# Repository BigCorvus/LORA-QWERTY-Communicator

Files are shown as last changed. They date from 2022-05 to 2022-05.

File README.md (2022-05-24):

# LORA-QWERTY-Communicator
A tidy, versatile and feature-packed LORA QWERTY communication device mainly based on a Blackberry Q10 keyboard, nRF52840, SX1262 and a 2.7'' Sharp Memory LCD (LS027B7DH01).
I created this because I wanted to practice a little and put some components that I had laying around to good use. The system had to have a low power consumption and outdoor usability, hence the component choices. The SX1262 draws 4,6mA in RX mode and the nRF52 can poll the keyboard while also drawing little power. Without optimizing anything I got 12mA. This can be further reduced by turning off some sensors. The unit can monitor its own power consumption and battery charge status via a BQ27441 Lithium Fuel Gauge.  
finished devices  

Some words about the memory LCDs: I got fake ones from Ali and only one out of three works properly! One consumes 20mA instead of ~400µA and one had some dead pixels after some days of usage (seen on the pictures). They are not that much cheaper (~25 vs ca 32$), so avoid them and only get genuine SHARP displays from digikey or so.  
There is a passive piezo buzzer (9032 type) and a vibration motor ("10x4mm" look on Aliexpress) for notification purposes. A BME280 can be soldered for altimeter functionality. A DS3231M RTC is supposed to keep time (the wires on the images are for optional backup battery connection). A MPU9250 9-DOF IMU was included to act as a tilt-compensated compass or for air mouse functionality. A GD25Q16CE QSPI flash (apparently optional, not required by the bootloader, works with mass storage TinyUSB test sketch) and an µSD card slot for storage of for example chat history or sensor values. An optional GPS module can be connected to the exposed connector at the top of the device. I used a BN220 which fits into the enclosure if you use an appropriate LiPo cell. All I2C sensor are on one I2C bus and are optional. They do not need to be populated. Time and altitude can just as well be fetched via GPS. The connector for the Q10 keyboard is a Hirose BM14B(0.8)-24DS-0.4V(53)     

open devices  
open devices 2  

The repository contains the EAGLE PCB design files, gerber, pick and place and BOM files, Solidworks design files and .STL for a perfectly fitting enclosure and an Arduino test sketch to test most of the system components. The enclosure lacks inserts for the pushbutton and slide swith. This I will add in the future. You require 4 2mmx10mm plastic screws to hold it together. The resulting device has a thickness of only about 13,5mm.  
While the hardware is confirmed working (only one minor bug had to be fixed in the prototype - conflicting I2C addresses), the firmware part is very raw and has yet to be developed. Unfortunately I lack time desperately for such hobby things at the moment. What I had in mind for this device is mainly something like an encrypted "apocalypse" LORA communicator, maybe even based on Meshtastic. It can also communicate with other BLE devices and acquire, log and share sensor data or act as a USB or BLE HID keyboard. The test firmware is based on the Adafruit nRF52 core v1.0.0. In order for the device to be programmable via the Arduino IDE, the Feather nRF52840 Express bootloader has to be flashed, which I usually do via a J-Link and the Arduino IDE ("Burn Bootloader"). The bootloader can be activated at any time double-pulling the reset pin low. In a future revision there should also be reset button for that purpose, now there is at least a test point. The variant files for the Feather nRF52840 express need to be modified as well before programming the board. They are provided with the test sketch together with a readme.  

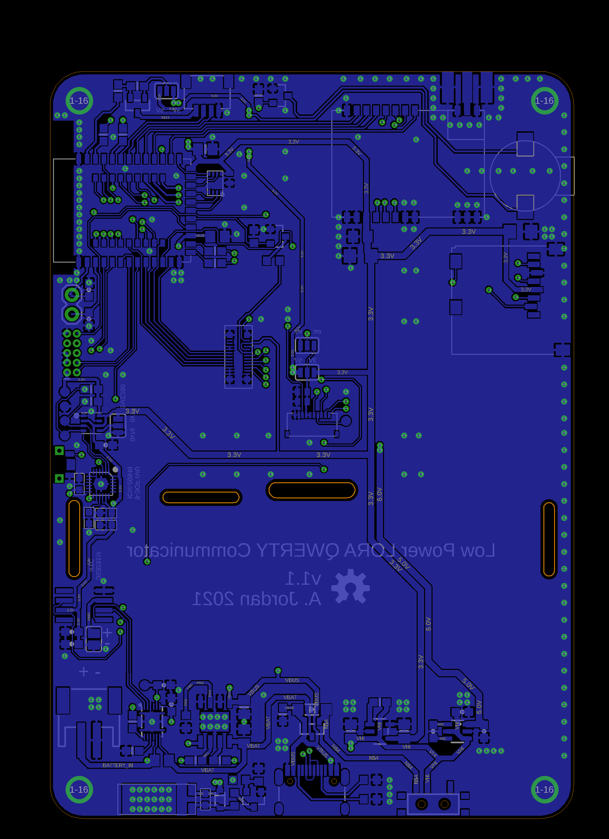
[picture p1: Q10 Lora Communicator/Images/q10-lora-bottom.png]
bottom
  
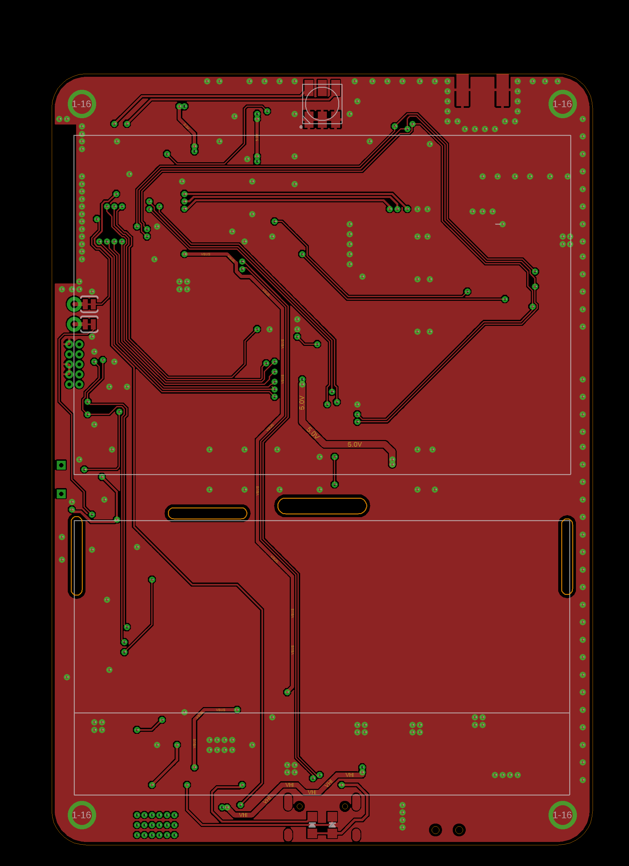
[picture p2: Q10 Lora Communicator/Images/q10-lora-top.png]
top
  
schematics

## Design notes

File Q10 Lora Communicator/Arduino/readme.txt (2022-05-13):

Before running the sketch, the adafruit feather express variant files have to be replaced with the provided ones first. They are located here under Windows:
C:\Users\xxxxxxxxx\AppData\Local\Arduino15\packages\adafruit\hardware\nrf52\1.0.0\variants

The feather nrf52840 express bootloader needs to be flashed via a segger jlink and the Arduino IDE.

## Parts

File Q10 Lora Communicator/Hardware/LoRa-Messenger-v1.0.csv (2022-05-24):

Part | Value | Device | Package | Description | DATASHEET | DIGIKEY | ELEMENT14 | OTHER | PROD_ID | SPICEPREFIX | TP_SIGNAL_NAME | URL | VALUE
1V8 | TPSQTP13R | TPSQTP13R | TP13R | Test pad
3V | TPSQTP13R | TPSQTP13R | TP13R | Test pad
ANT |  | SMACONNECTOR_EDGE | SMA_EDGELAUNCH | SMA Connector
C1 | 10µ | C-EUC0805 | C0805 | CAPACITOR, European symbol |  |  |  |  |  | C
C2 | 1.0uF | 1.0UF-16V-10%(0603) | 0603-CAP | CAP-00868 |  |  |  |  | CAP-00868 |  |  |  | 1.0uF
C3 | 100n | C-EUC0402 | C0402 | CAPACITOR, European symbol
C4 | 0.47uF | CAP0603-CAP | 0603-CAP | Capacitor |  |  |  |  | CAP-13216
C5 | 1.0uF | 1.0UF-16V-10%(0603) | 0603-CAP | CAP-00868 |  |  |  |  | CAP-00868 |  |  |  | 1.0uF
C6 | 10uF | CAP_CERAMIC0805-NOOUTLINE | 0805-NO | Ceramic Capacitors
C7 | 10uF | CAP_CERAMIC0805-NOOUTLINE | 0805-NO | Ceramic Capacitors
C8 | 10uF | CAP_CERAMIC0805-NOOUTLINE | 0805-NO | Ceramic Capacitors
C9 | 10µ | C-EUC0805 | C0805 | CAPACITOR, European symbol |  |  |  |  |  | C
C10 | 10uF | CAP_CERAMIC0805-NOOUTLINE | 0805-NO | Ceramic Capacitors
C11 | 10uF | 1.0UF-16V-10%(0603) | 0603-CAP | CAP-00868 |  |  |  |  | CAP-00868 |  |  |  | 1.0uF
C12 | 10nF 10% | CAP-0603 | C0603 | Ceramic Capacitors
C13 | 1µF | C-EUC0402 | C0402 | CAPACITOR, European symbol
C14 | 130pf | 1.0UF-16V-10%(0603) | 0603-CAP | CAP-00868 |  |  |  |  | CAP-00868 |  |  |  | 1.0uF
C15 | 100n | C-EUC0402 | C0402 | CAPACITOR, European symbol
C16 | 100nF 10% | CAP-0603 | C0603 | Ceramic Capacitors
C17 | 10uF | 1.0UF-16V-10%(0603) | 0603-CAP | CAP-00868 |  |  |  |  | CAP-00868 |  |  |  | 1.0uF
C18 | 100nF 10% | CAP-0603 | C0603 | Ceramic Capacitors
C19 | 130pf | 1.0UF-16V-10%(0603) | 0603-CAP | CAP-00868 |  |  |  |  | CAP-00868 |  |  |  | 1.0uF
C20 | 100µ | C-EUC1206 | C1206 | CAPACITOR, European symbol |  |  |  |  |  | C
C21 | 100µ | C-EUC1206 | C1206 | CAPACITOR, European symbol |  |  |  |  |  | C
C22 | 100n | 1.0UF-16V-10%(0603) | 0603-CAP | CAP-00868 |  |  |  |  | CAP-00868 |  |  |  | 1.0uF
C23 | 10µ | C-EUC0805 | C0805 | CAPACITOR, European symbol |  |  |  |  |  | C
C24 | 100nF 10% | CAP-0603 | C0603 | Ceramic Capacitors
C25 | 100nF 10% | CAP-0603 | C0603 | Ceramic Capacitors
C26 | 100n | 1.0UF-16V-10%(0603) | 0603-CAP | CAP-00868 |  |  |  |  | CAP-00868 |  |  |  | 1.0uF
C27 | 1µ | 1.0UF-16V-10%(0603) | 0603-CAP | CAP-00868 |  |  |  |  | CAP-00868 |  |  |  | 1.0uF
D1 | MBR120 | DIODE-SCHOTTKYSOD-123 | SOD-123
D3 | RED | LED0805_NOOUTLINE | CHIPLED_0805_NOOUTLINE | LED
D5 | RED | LED0805_NOOUTLINE | CHIPLED_0805_NOOUTLINE | LED
D6 | BAT20J | DIODE-SCHOTTKY-BAT20J | SOD-323 | Schottky diodes in SFE's production catalog |  |  |  |  | DIO-11623 |  |  |  | BAT20J
DWN2 | LS12T2 | LS12T2 | LS12T2
EXTC. | TPSQTP13R | TPSQTP13R | TP13R | Test pad
GND | TPSQTP13R | TPSQTP13R | TP13R | Test pad
IC1 | AP3602 | AP3602 | SOT23-6
IC2 | GD25Q16 | SPIFLASH_8PINUX | USON8 | SOIC8 SPI Flash
J2 |  | USB_C16PIN | USB-C-16P | USB Type C 16Pin Connector |  |  |  |  | CONN-14122
J3 | CORTEX_JTAG_DEBUG_MINIMUM_PTH_NS | CORTEX_JTAG_DEBUG_MINIMUM_PTH_NS | 2X5-PTH-1.27MM-NO_SILK | Cortex Debug Connector - 10 pin
JP2 |  | M02PTH | 1X02 | Standard 2-pin 0.1 header. Use with"
LED1 | RGBLED5050 | RGBLED5050 | RGBLED5050 | For 5050 RGB LEDs, the order of the LEDs may vary from one manufacturer to another!
Q2 | DMG2305 | MOSFET-P | SOT23-R | P-Channel Mosfet
Q3 | DMG2305 | MOSFET-P | SOT23-R | P-Channel Mosfet
R1 | 100k | RESISTOR_0603_NOOUT | 0603-NO | Resistors
R2 | 100k | RESISTOR_0603_NOOUT | 0603-NO | Resistors
R3 | 1K | RESISTOR_0603_NOOUT | 0603-NO | Resistors
R4 | 1.1k | R-EU_R0603 | R0603 | RESISTOR, European symbol |  |  |  |  |  | R
R5 | 10mOhm | R-EU_R0805 | R0805 | RESISTOR, European symbol |  |  |  |  |  | R
R6 | 4k7 | RESISTOR_0603_NOOUT | 0603-NO | Resistors
R7 | 1K | RESISTOR_0603_NOOUT | 0603-NO | Resistors
R8 | 100k | R-EU_R0603 | R0603 | RESISTOR, European symbol
R9 | 4k7 | RESISTOR_0603_NOOUT | 0603-NO | Resistors
R10 | 10k | RESISTOR_0603_NOOUT | 0603-NO | Resistors
R11 | 10k | RESISTOR_0603_NOOUT | 0603-NO | Resistors
R12 | 5.1k | R-EU_R0603 | R0603 | RESISTOR, European symbol |  |  |  |  |  | R
R13 | 5.1k | R-EU_R0603 | R0603 | RESISTOR, European symbol |  |  |  |  |  | R
R14 | 68 | RESISTOR_0603_NOOUT | 0603-NO | Resistors
R15 | 68 | RESISTOR_0603_NOOUT | 0603-NO | Resistors
R16 | 1K | RESISTOR_0603_NOOUT | 0603-NO | Resistors
R17 | 1K | RESISTOR_0603_NOOUT | 0603-NO | Resistors
R18 | 47 | R-EU_R0603 | R0603 | RESISTOR, European symbol
R19 | 10k | R-EU_R0603 | R0603 | RESISTOR, European symbol
R20 | 100k | RESISTOR_0603_NOOUT | 0603-NO | Resistors
R21 | 10 | R-EU_R0603 | R0603 | RESISTOR, European symbol
R22 | 10k | R-EU_R0603 | R0603 | RESISTOR, European symbol
R23 | 68 | RESISTOR_0603_NOOUT | 0603-NO | Resistors
R26 | 1k | RESISTOR_0603_NOOUT | 0603-NO | Resistors
SCL | TPSQTP13R | TPSQTP13R | TP13R | Test pad
SDA | TPSQTP13R | TPSQTP13R | TP13R | Test pad
SJ1 |  | SOLDERJUMPER_2WAY-OLDS | SJ_3 | Solder Jumper
SJ2 |  | SOLDERJUMPER_2WAY-OLDS | SJ_3 | Solder Jumper
SJ3 |  | SOLDERJUMPER_2WAY-OLDS | SJ_3 | Solder Jumper
SJ4 |  | SJ | SJ | SMD solder JUMPER
SJ5 |  | SOLDERJUMPER_2WAY-OLDS | SJ_3 | Solder Jumper
SJ7 | SOLDERJUMPERTRACE | SOLDERJUMPERTRACE | SJ_2S-TRACE | Solder Jumper
SJ8 | SOLDERJUMPERTRACE | SOLDERJUMPERTRACE | SJ_2S-TRACE | Solder Jumper
U$2 | BUZZER | BUZZER | BUZZER |  | 9032 type
U$7 | Q10KEYBOARD | Q10KEYBOARD | Q10KEYBOARD |  | Hirose BM14B(0.8)-24DS-0.4V(53)
U$10 | AYF531035_SHARP_MEM_DISP | AYF531035_SHARP_MEM_DISP | AYF531035_Y5BW
U$14 | NRF52840 | NRF52840 | NRF52840MOD
U$17 | JST-SH-3 | JST-SH-3 | JST-SH-3
U$28 | N-CHANNEL-MOSFET-BSS138 | N-CHANNEL-MOSFET-BSS138 | SOT23-3 | N-Channel MOSFET Mode Field Effect Transistor | http://www.fairchildsemi.com/ds/BS/BSS138.pdf | BSS138TR-ND | 2323154 |  |  |  |  | http://au.element14.com/fairchild-semiconductor/bss138/mosfet-n-ch-50v-220ma-sot-23/dp/2323154
U$36 | SX1292-EBYTE | SX1292-EBYTE | SX1262_EBYTE
U$41 | N-CHANNEL-MOSFET-BSS138 | N-CHANNEL-MOSFET-BSS138 | SOT23-3 | N-Channel MOSFET Mode Field Effect Transistor | http://www.fairchildsemi.com/ds/BS/BSS138.pdf | BSS138TR-ND | 2323154 |  |  |  |  | http://au.element14.com/fairchild-semiconductor/bss138/mosfet-n-ch-50v-220ma-sot-23/dp/2323154
U$45 | SWITCH_SPDT | SWITCH_SPDT | KPS-1290 | SWCH-10651 |  |  |  |  | SWCH-10651
U$46 | VIBRO | VIBRO | VIBRO |  |  |  |  |  | 10x4mm surface mount vibration motor
U$47 | TP4056BETTER_TP4056 | TP4056BETTER_TP4056 | TP4056BETTER_SO-08
U$69 | DS3231M | DS3231M | SO8
U$74 | N-CHANNEL-MOSFET-BSS138 | N-CHANNEL-MOSFET-BSS138 | SOT23-3 | N-Channel MOSFET Mode Field Effect Transistor | http://www.fairchildsemi.com/ds/BS/BSS138.pdf | BSS138TR-ND | 2323154 |  |  |  |  | http://au.element14.com/fairchild-semiconductor/bss138/mosfet-n-ch-50v-220ma-sot-23/dp/2323154
U1 | BQ27441-G1 | BQ27441-G1 | PDSO-N12 |  |  |  |  |  | IC-13220
U2 | AP2112(3.3V) | VREG_SOT23-5 | SOT23-5 | SOT23-5 Fixed Voltage Regulators
U3 | BME280 | BME280 | BME280 | BME280 - Environmental Sensor (I2C + SPI)
U4 | MPU-9250 | MPU-9250 | LEAD-QFN24
X1 | JSTPH | CON_JST_PH_2PIN | JSTPH2 | JST 2-Pin Right-Angle Connector
X4 | microsd | MICROSD | MICROSD | MicroSD/Transflash Card Holder with SPI pinout

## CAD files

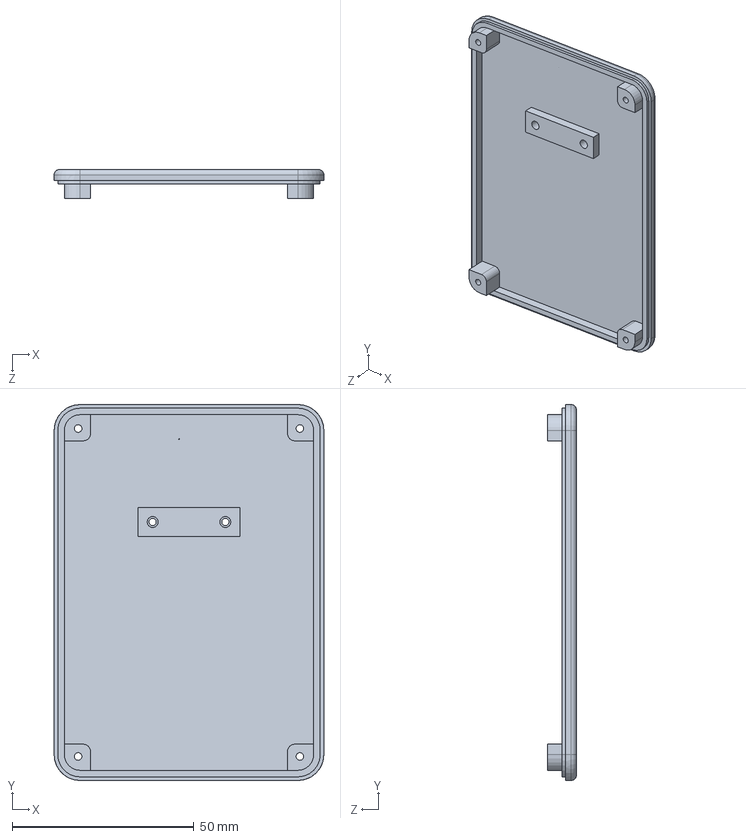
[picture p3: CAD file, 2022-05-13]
Q10 Lora Communicator/Hardware/enclosure/LORAmessengerBot.SLDPRT
74.2 x 103.4 x 8.00 mm

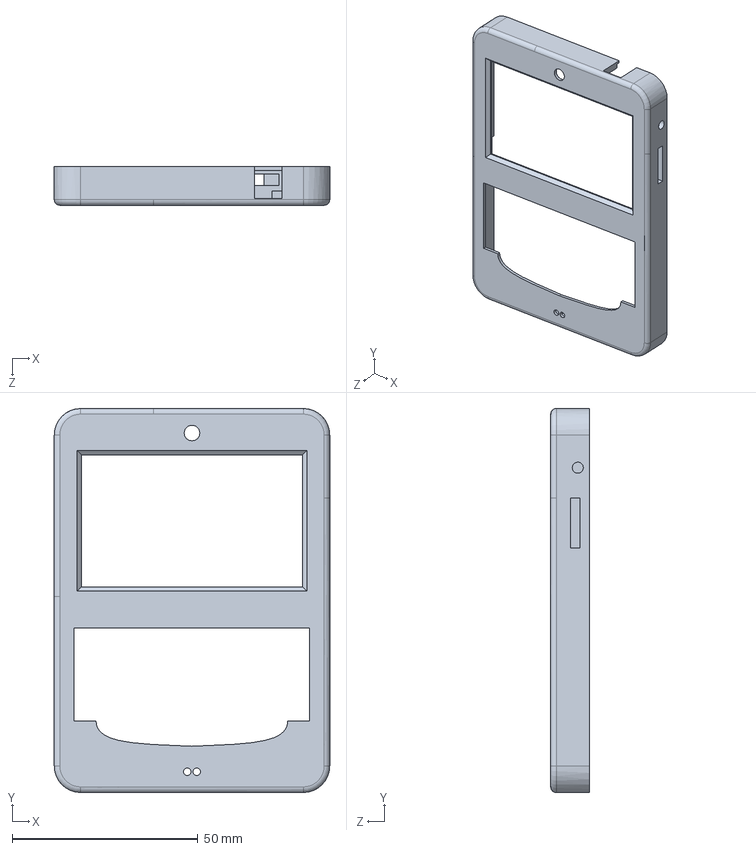
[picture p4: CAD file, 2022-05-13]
Q10 Lora Communicator/Hardware/enclosure/LORAmessengerTop.SLDPRT
74.2 x 103.4 x 10.4 mm

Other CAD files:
Q10 Lora Communicator/Hardware/enclosure/LORAmessengerBot.STL
Q10 Lora Communicator/Hardware/enclosure/LORAmessengerTop.STL

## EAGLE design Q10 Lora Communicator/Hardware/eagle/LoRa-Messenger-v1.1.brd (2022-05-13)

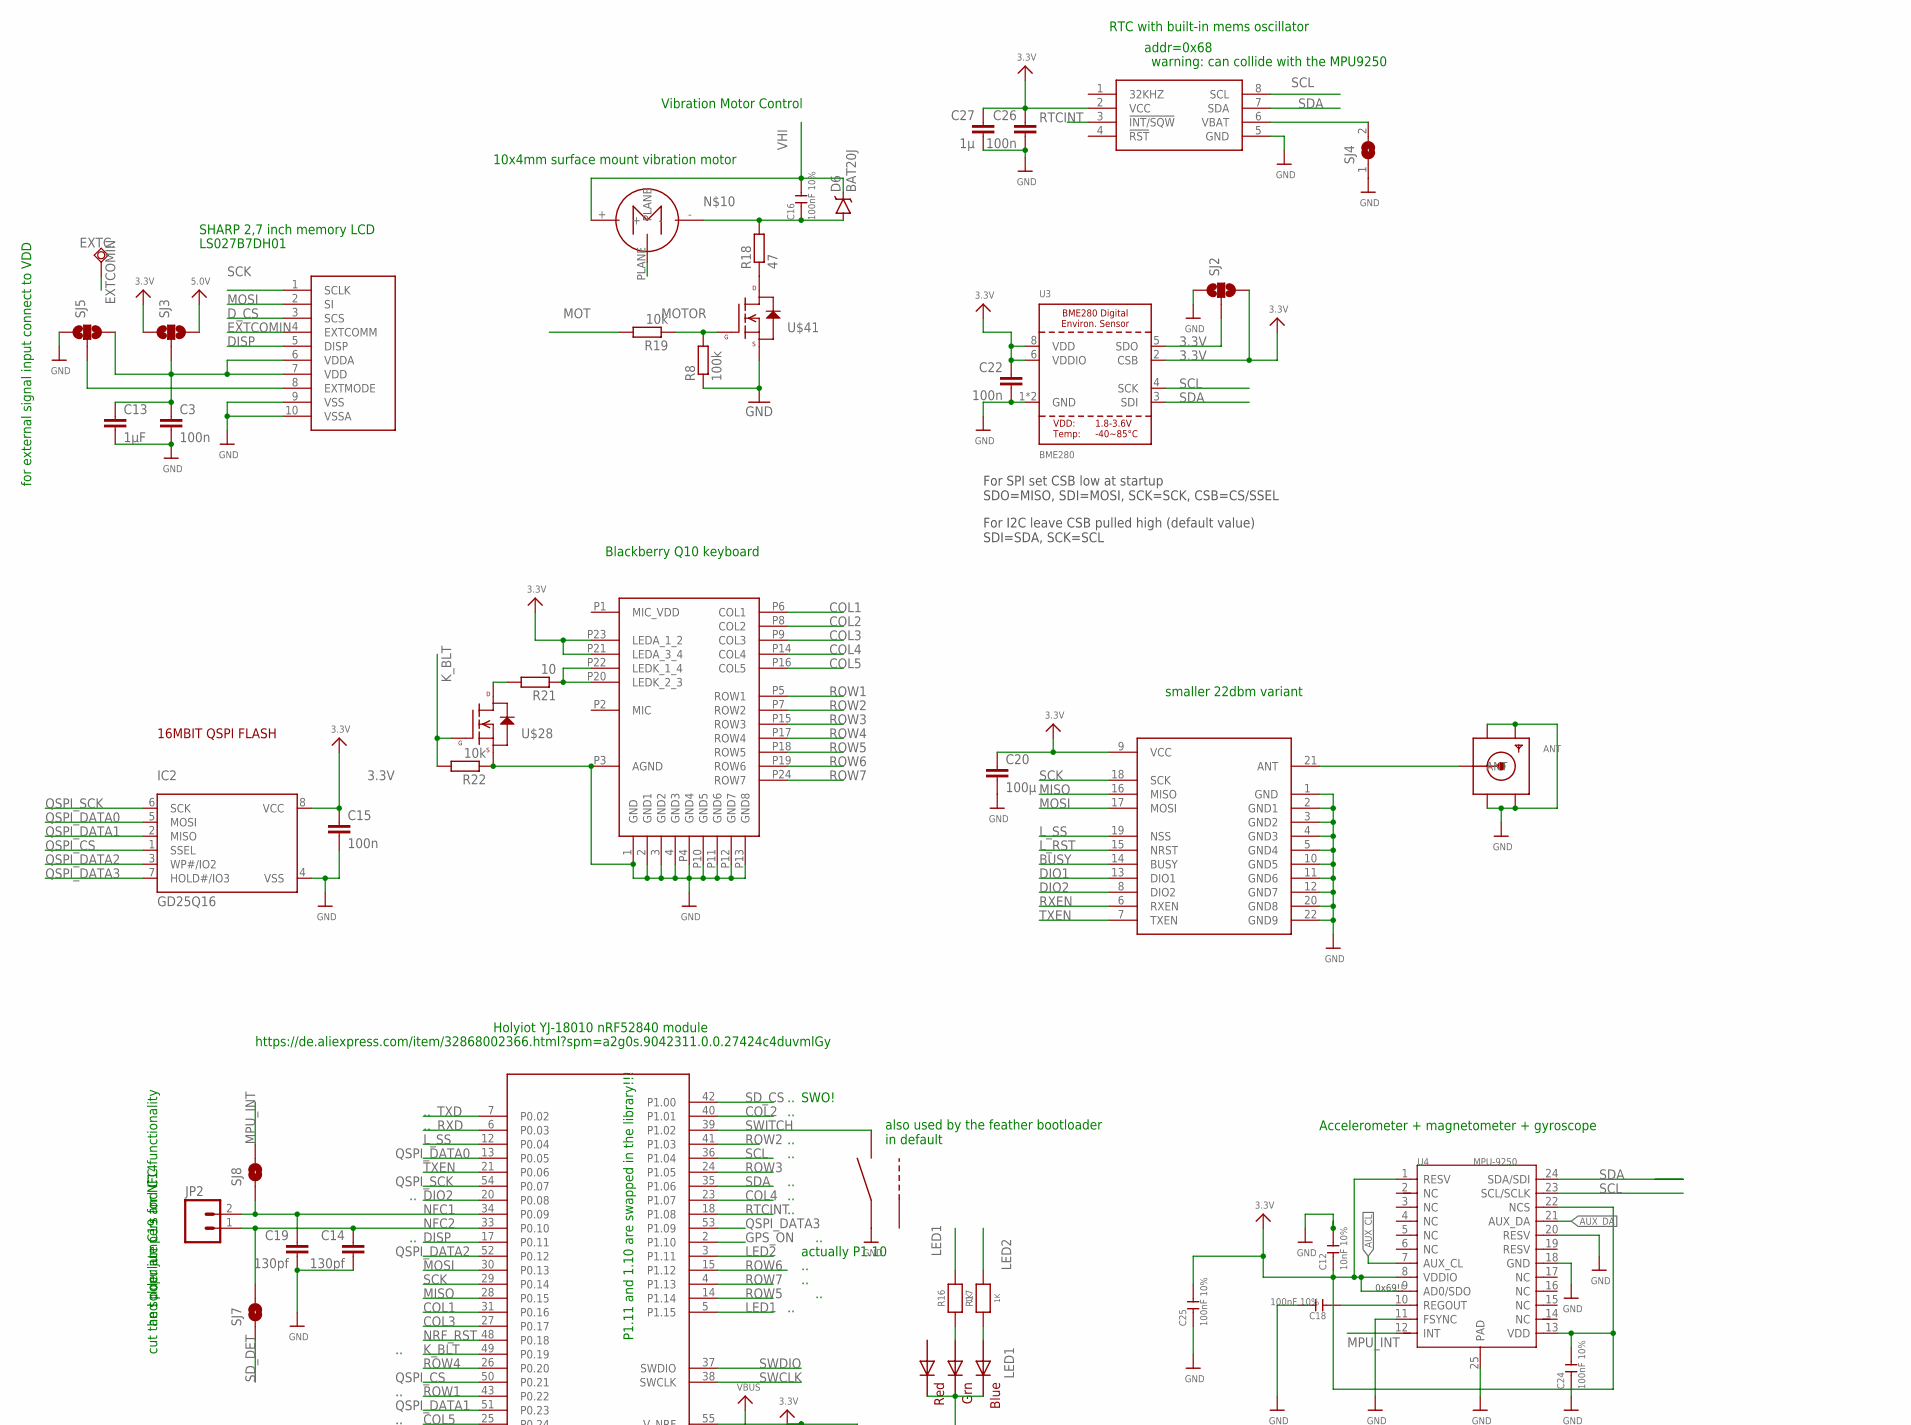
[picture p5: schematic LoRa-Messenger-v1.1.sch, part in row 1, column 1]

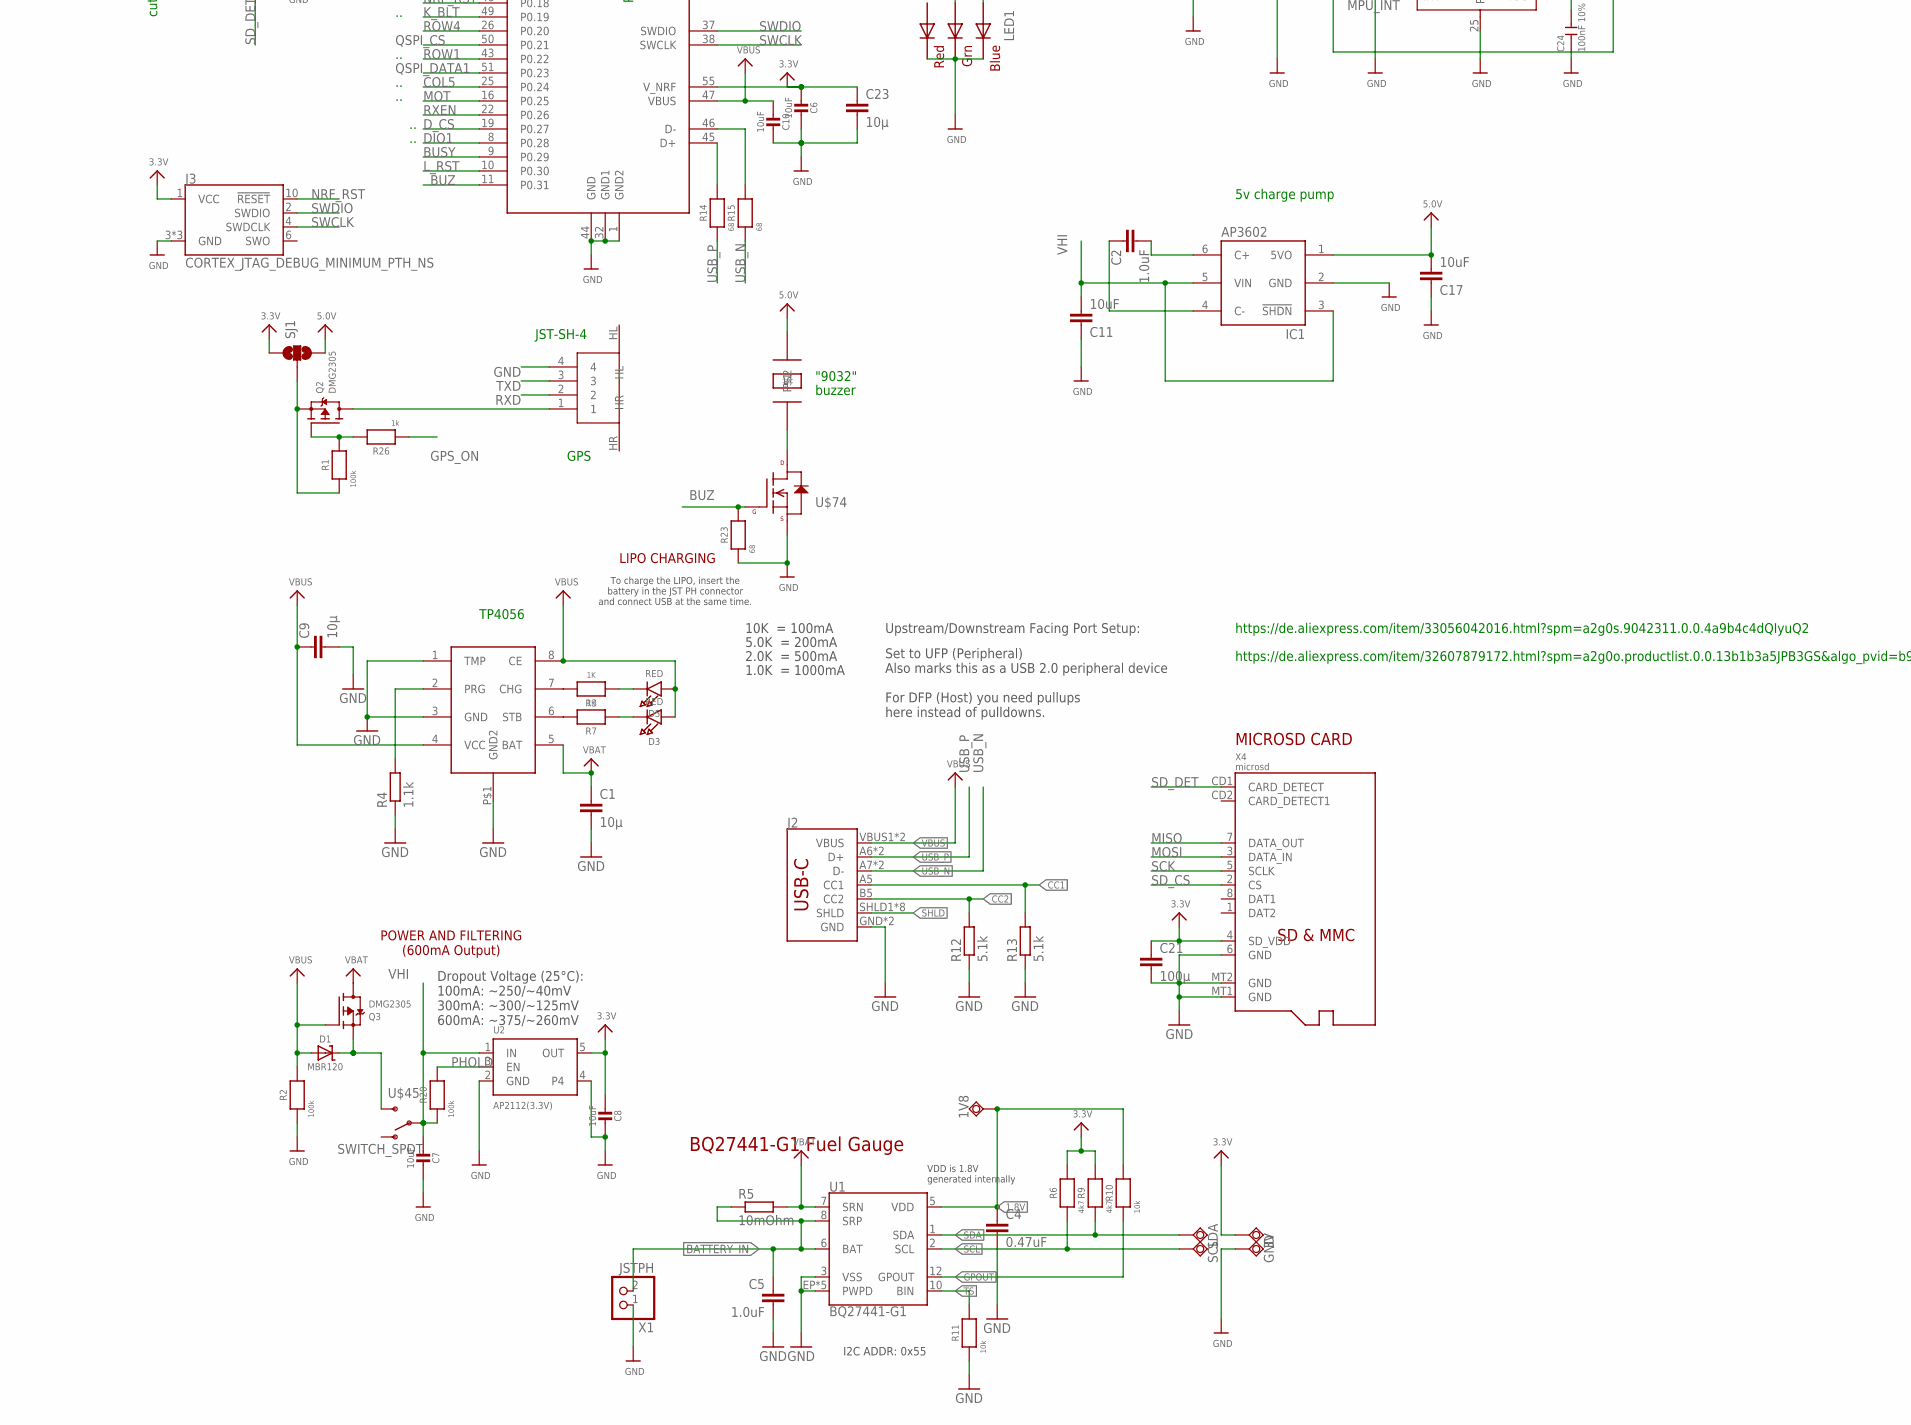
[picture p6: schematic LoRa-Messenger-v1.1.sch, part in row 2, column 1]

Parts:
1V8, 3V: TPSQTP13R; TP13R
ANT: SMACONNECTOR_EDGE; SMA_EDGELAUNCH
C1, C9, C23: 10µ; C0805
C2, C5: 1.0uF; 0603-CAP
C3, C15: 100n; C0402
C4: 0.47uF; 0603-CAP
C6, C7, C8, C10: 10uF; 0805-NO
C11, C17: 10uF; 0603-CAP
C12: 10nF 10%; C0603
C13: 1µF; C0402
C14, C19: 130pf; 0603-CAP
C16, C18, C24, C25: 100nF 10%; C0603
C20, C21: 100µ; C1206
C22, C26: 100n; 0603-CAP
C27: 1µ; 0603-CAP
D1: MBR120; SOD-123
D3, D5: RED; CHIPLED_0805_NOOUTLINE
D6: BAT20J; SOD-323
DWN2: LS12T2
EXTC.: TPSQTP13R; TP13R
GND: TPSQTP13R; TP13R
IC1: AP3602; SOT23-6
IC2: GD25Q16; USON8
J2: USB_C16PIN; USB-C-16P
J3: CORTEX_JTAG_DEBUG_MINIMUM_PTH_NS; 2X5-PTH-1.27MM-NO_SILK
JP2: M02PTH; 1X02
LED1: RGBLED5050
Q2, Q3: DMG2305; SOT23-R
R1, R2, R20: 100k; 0603-NO
R3, R7, R16, R17: 1K; 0603-NO
R4: 1.1k; R0603
R5: 10mOhm; R0805
R6, R9: 4k7; 0603-NO
R8: 100k; R0603
R10, R11: 10k; 0603-NO
R12, R13: 5.1k; R0603
R14, R15, R23: 68; 0603-NO
R18: 47; R0603
R19, R22: 10k; R0603
R21: 10; R0603
R26: 1k; 0603-NO
SCL: TPSQTP13R; TP13R
SDA: TPSQTP13R; TP13R
SJ1, SJ2, SJ3, SJ5: SOLDERJUMPER_2WAY-OLDS; SJ_3
SJ4: SJ
SJ7, SJ8: SOLDERJUMPERTRACE; SJ_2S-TRACE
U1: BQ27441-G1; PDSO-N12
U2: AP2112(3.3V); SOT23-5
U3: BME280
U4: MPU-9250; LEAD-QFN24
U$2: BUZZER
U$7: Q10KEYBOARD
U$10: AYF531035_SHARP_MEM_DISP; AYF531035_Y5BW
U$14: NRF52840; NRF52840MOD
U$17: JST-SH-3
U$28, U$41, U$74: N-CHANNEL-MOSFET-BSS138; SOT23-3
U$36: SX1292-EBYTE; SX1262_EBYTE
U$45: SWITCH_SPDT; KPS-1290
U$46: VIBRO
U$47: TP4056BETTER_TP4056; TP4056BETTER_SO-08
U$69: DS3231M; SO8
X1: JSTPH; JSTPH2
X4: microsd; MICROSD

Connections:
1.8V: 1V8.TP, C4.1, R10.2, U1.5 (VDD)
3.3V: 3V.TP, C6.2, C8.2, C12.1, C15.1, C20.1, C21.1, C22.1, C23.1, C24.2, C25.2, C26.1, C27.1, IC2.8 (VCC), J3.1 (VCC), R6.2, R9.2, SJ1.1, SJ2.3, SJ3.1, U2.5 (OUT), U3.2 (CSB), U3.6 (VDDIO), U3.8 (VDD), U4.1 (RESV), U4.8 (VDDIO), U4.9 (AD0/SDO), U4.13 (VDD), U4.22 (NCS), U$7.P21 (LEDA_3_4), U$7.P23 (LEDA_1_2), U$14.55 (V_NRF), U$36.9 (VCC), U$69.2 (VCC), X4.4 (SD_VDD)
5.0V: C17.2, IC1.1 (5VO), SJ1.3, SJ3.3, U$2.P$1
AUX_CL: U4.7 (AUX_CL)
AUX_DA: U4.21 (AUX_DA)
BATTERY_IN: C5.1, R5.1, U1.6 (BAT), U1.8 (SRP), X1.2
BUSY: U$14.9 (P0.29), U$36.14 (BUSY)
BUZ: R23.2, U$14.11 (P0.31), U$74.1 (G)
CC1: J2.A5 (CC1), R13.2
CC2: J2.B5 (CC2), R12.2
COL1: U$7.P6 (COL1), U$14.31 (P0.16)
COL2: U$7.P8 (COL2), U$14.40 (P1.01)
COL3: U$7.P9 (COL3), U$14.27 (P0.17)
COL4: U$7.P14 (COL4), U$14.23 (P1.07)
COL5: U$7.P16 (COL5), U$14.25 (P0.24)
DIO1: U$14.8 (P0.28), U$36.13 (DIO1)
DIO2: U$14.20 (P0.08), U$36.8 (DIO2)
DISP: U$10.5 (DISP), U$14.17 (P0.11)
D_CS: U$10.3 (SCS), U$14.19 (P0.27)
EXTCOMIN: EXTC..TP, U$10.4 (EXTCOMM)
GND: ANT.GND@1 (GND4), ANT.GND@2 (GND3), ANT.GND@3 (GND2), ANT.GND@4 (GND1), C1.2, C3.2, C4.2, C5.2, C6.1, C7.1, C8.1, C9.2, C10.1, C11.1, C12.2, C13.2, C14.2, C15.2, C17.1, C18.2, C19.2, C20.2, C21.2, C22.2, C23.2, C24.1, C25.1, C26.2, C27.2, DWN2.2, GND.TP, IC1.2 (GND), IC2.4 (VSS), J2.GND, J2.GND2 (GND), J3.3 (GND), J3.5 (GND), J3.9 (GND), LED1.4 (BLUE_C), LED1.5 (RED_C), LED1.6 (GREEN_C), R2.1, R4.1, R8.1, R11.1, R12.1, R13.1, R22.1, R23.1, SJ2.1, SJ4.1, SJ5.1, U1.3 (VSS), U1.EP (PWPD), U1.EP1 (PWPD), U1.EP2 (PWPD), U1.EP3 (PWPD), U1.EP4 (PWPD), U2.2 (GND), U2.4, U3.1 (GND), U3.7 (GND), U4.11 (FSYNC), U4.18 (GND), U4.20 (RESV), U4.25 (PAD), U$7.1 (GND), U$7.2 (GND1), U$7.3 (GND2), U$7.4 (GND3), U$7.P3 (AGND), U$7.P4 (GND4), U$7.P10 (GND5), U$7.P11 (GND6), U$7.P12 (GND7), U$7.P13 (GND8), U$10.9 (VSS), U$10.10 (VSSA), U$14.1 (GND2), U$14.32 (GND1), U$14.44 (GND), U$17.4, U$28.2 (S), U$36.1 (GND), U$36.2 (GND1), U$36.3 (GND2), U$36.4 (GND3), U$36.5 (GND4), U$36.10 (GND5), U$36.11 (GND6), U$36.12 (GND7), U$36.20 (GND8), U$36.22 (GND9), U$41.2 (S), U$47.1 (TMP), U$47.3 (GND), U$47.P$1 (GND2), U$69.5 (GND), U$74.2 (S), X1.1, X4.6 (GND), X4.MT1 (GND), X4.MT2 (GND)
GPOUT: R10.1, U1.12 (GPOUT)
GPS_ON: R26.1, U$14.2 (P1.10)
K_BLT: R22.2, U$14.49 (P0.19), U$28.1 (G)
LED1: R16.2, U$14.5 (P1.15)
LED2: R17.2, U$14.3 (P1.11)
L_RST: U$14.10 (P0.30), U$36.15 (NRST)
L_SS: U$14.12 (P0.04), U$36.19 (NSS)
MISO: U$14.28 (P0.15), U$36.16 (MISO), X4.7 (DATA_OUT)
MOSI: U$10.2 (SI), U$14.30 (P0.13), U$36.17 (MOSI), X4.3 (DATA_IN)
MOT: R19.2, U$14.16 (P0.25)
MOTOR: R8.2, R19.1, U$41.1 (G)
MPU_INT: SJ8.2, U4.12 (INT)
unnamed: R3.2, U$47.7 (CHG)
unnamed: C2.2, IC1.6 (C+)
unnamed: C2.1, IC1.4 (C-)
unnamed: D1.C, Q3.2 (S), U$45.S
unnamed: Q2.1 (G), R1.2, R26.2
unnamed: R14.2, U$14.45 (D+)
unnamed: R15.2, U$14.46 (D-)
unnamed: R7.2, U$47.6 (STB)
unnamed: R18.1, U$41.3 (D)
unnamed: C16.1, D6.A, R18.2, U$46.-
unnamed: D5.C, R3.1
unnamed: D3.C, R7.1
unnamed: LED1.1 (GREEN_A), R16.1
unnamed: Q2.3 (D), U$17.1
unnamed: R21.1, U$7.P20 (LEDK_2_3), U$7.P22 (LEDK_1_4)
unnamed: Q2.2 (S), R1.1, SJ1.2
unnamed: R21.2, U$28.3 (D)
unnamed: ANT.P (ANT), U$36.21 (ANT)
unnamed: LED1.3 (BLUE_A), R17.1
unnamed: SJ2.2, U3.5 (SDO)
unnamed: U$2.P$2, U$74.3 (D)
unnamed: C18.1, U4.10 (REGOUT)
unnamed: SJ4.2, U$69.6 (VBAT)
unnamed: C3.1, C13.1, SJ3.2, SJ5.3, U$10.6 (VDDA), U$10.7 (VDD)
unnamed: SJ5.2, U$10.8 (EXTMODE)
NFC1: C19.1, JP2.2, SJ8.1, U$14.34 (P0.09)
NFC2: C14.1, JP2.1, SJ7.2, U$14.33 (P0.10)
NRF_RST: J3.10 (!RESET), U$14.48 (P0.18)
PHOLD: R20.2, U2.3 (EN)
PLANE: U$46.PLANE
PRG: R4.2, U$47.2 (PRG)
QSPI_CS: IC2.1 (SSEL), U$14.50 (P0.21)
QSPI_DATA0: IC2.5 (MOSI), U$14.13 (P0.05)
QSPI_DATA1: IC2.2 (MISO), U$14.51 (P0.23)
QSPI_DATA2: IC2.3 (WP#/IO2), U$14.52 (P0.12)
QSPI_DATA3: IC2.7 (HOLD#/IO3), U$14.53 (P1.09)
QSPI_SCK: IC2.6 (SCK), U$14.54 (P0.07)
ROW1: U$7.P5 (ROW1), U$14.43 (P0.22)
ROW2: U$7.P7 (ROW2), U$14.41 (P1.03)
ROW3: U$7.P15 (ROW3), U$14.24 (P1.05)
ROW4: U$7.P17 (ROW4), U$14.26 (P0.20)
ROW5: U$7.P18 (ROW5), U$14.14 (P1.14)
ROW6: U$7.P19 (ROW6), U$14.15 (P1.12)
ROW7: U$7.P24 (ROW7), U$14.4 (P1.13)
RTCINT: U$14.18 (P1.08), U$69.3 (!INT/SQW)
RXD: U$14.6 (P0.03), U$17.2
RXEN: U$14.22 (P0.26), U$36.6 (RXEN)
SCK: U$10.1 (SCLK), U$14.29 (P0.14), U$36.18 (SCK), X4.5 (SCLK)
SCL: R6.1, SCL.TP, U1.2 (SCL), U3.4 (SCK), U4.23 (SCL/SCLK), U$14.36 (P1.04), U$69.8 (SCL)
SDA: R9.1, SDA.TP, U1.1 (SDA), U3.3 (SDI), U4.24 (SDA/SDI), U$14.35 (P1.06), U$69.7 (SDA)
SD_CS: U$14.42 (P1.00), X4.2 (CS)
SD_DET: SJ7.1, X4.CD1 (CARD_DETECT)
SHLD: J2.SHLD1 (SHLD), J2.SHLD2 (SHLD), J2.SHLD3 (SHLD), J2.SHLD4 (SHLD), J2.SHLD5 (SHLD), J2.SHLD6 (SHLD), J2.SHLD7 (SHLD), J2.SHLD8 (SHLD)
SWCLK: J3.4 (SWDCLK), U$14.38 (SWCLK)
SWDIO: J3.2 (SWDIO), U$14.37 (SWDIO)
SWITCH: DWN2.1, U$14.39 (P1.02)
TS: R11.2, U1.10 (BIN)
TXD: U$14.7 (P0.02), U$17.3
TXEN: U$14.21 (P0.06), U$36.7 (TXEN)
USB_N: J2.A7 (D-), J2.B7 (D-), R15.1
USB_P: J2.A6 (D+), J2.B6 (D+), R14.1
VBAT: C1.1, Q3.3 (D), R5.2, U1.7 (SRN), U$47.5 (BAT)
VBUS: C9.1, C10.2, D1.A, D3.A, D5.A, J2.VBUS1 (VBUS), J2.VBUS2 (VBUS), Q3.1 (G), R2.2, U$14.47 (VBUS), U$47.4 (VCC), U$47.8 (CE)
VHI: C7.2, C11.2, C16.2, D6.C, IC1.3 (!SHDN), IC1.5 (VIN), R20.1, U2.1 (IN), U$45.P, U$46.+

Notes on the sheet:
POWER AND FILTERING (600mA Output)
Dropout Voltage (25°C): 100mA: ~250/~40mV 300mA: ~300/~125mV 600mA: ~375/~260mV
10K = 100mA
5.0K = 200mA
2.0K = 500mA
1.0K = 1000mA
LIPO CHARGING
To charge the LIPO, insert the battery in the JST PH connector and connect USB at the same time.
BQ27441-G1 Fuel Gauge
VDD is 1.8V generated internally
I2C ADDR: 0x55
Holyiot YJ-18010 nRF52840 module
P1.11 and 1.10 are swapped in the library!!!
GPS
MICROSD CARD
Set to UFP (Peripheral) Also marks this as a USB 2.0 peripheral device For DFP (Host) you need pullups here instead of pulldowns.
Upstream/Downstream Facing Port Setup:
JST-SH-4
TP4056
smaller 22dbm variant
also used by the feather bootloader in default
For SPI set CSB low at startup SDO=MISO, SDI=MOSI, SCK=SCK, CSB=CS/SSEL
For I2C leave CSB pulled high (default value) SDI=SDA, SCK=SCL
actually P1.10
https://de.aliexpress.com/item/33056042016.html?spm=a2g0s.9042311.0.0.4a9b4c4dQIyuQ2
https://de.aliexpress.com/item/32868002366.html?spm=a2g0s.9042311.0.0.27424c4duvmlGy
https://de.aliexpress.com/item/32607879172.html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,searchweb201602_,searchweb201603_
16MBIT QSPI FLASH
for external signal input connect to VDD
Vibration Motor Control
0x69!!
Accelerometer + magnetometer + gyroscope
RTC with built-in mems oscillator
SWO!
cut the solder jumpers for NFC functionality
and populate C19 and C14
Blackberry Q10 keyboard
SHARP 2,7 inch memory LCD
addr=0x68
5v charge pump

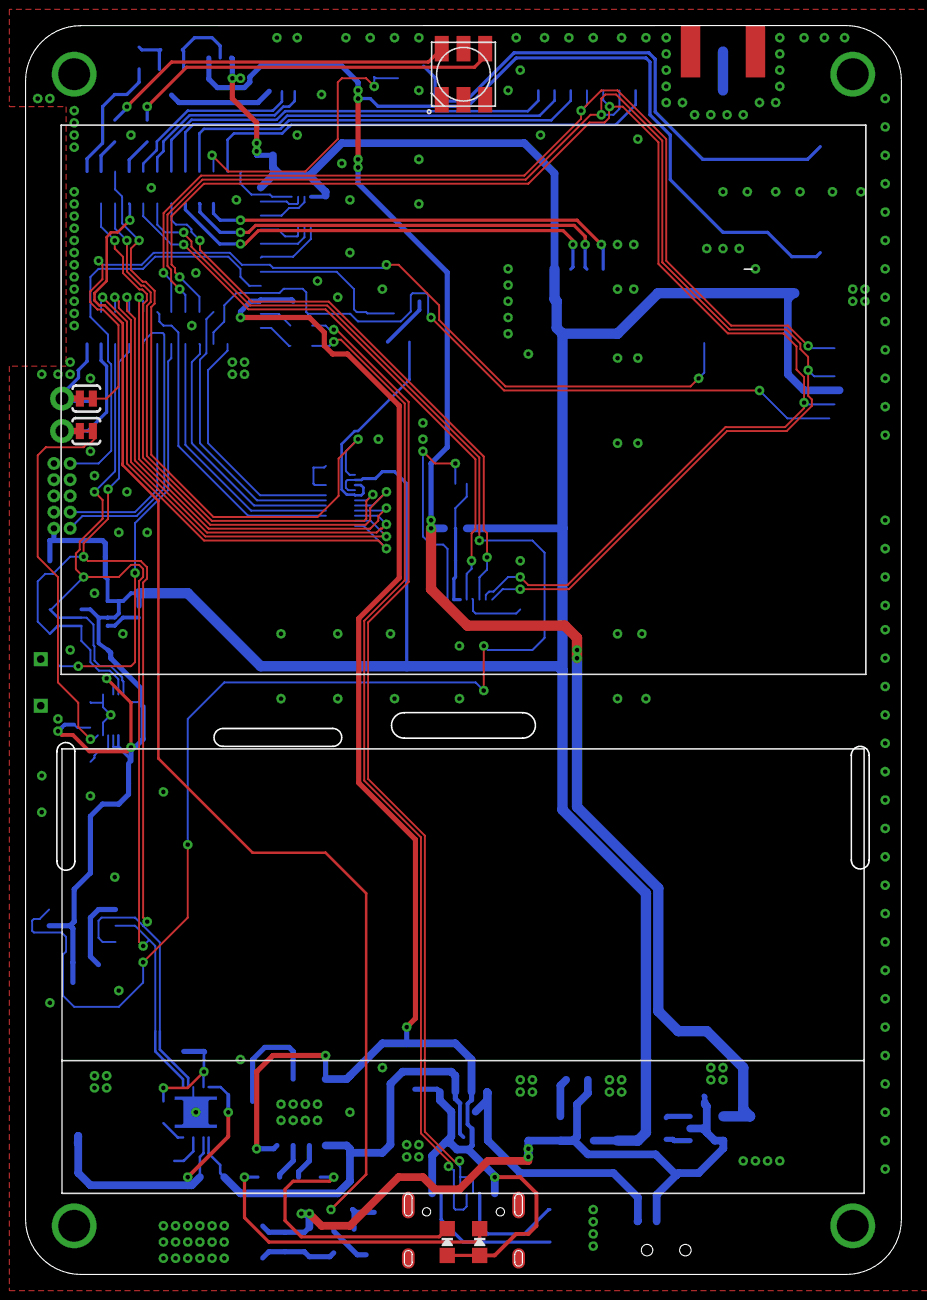
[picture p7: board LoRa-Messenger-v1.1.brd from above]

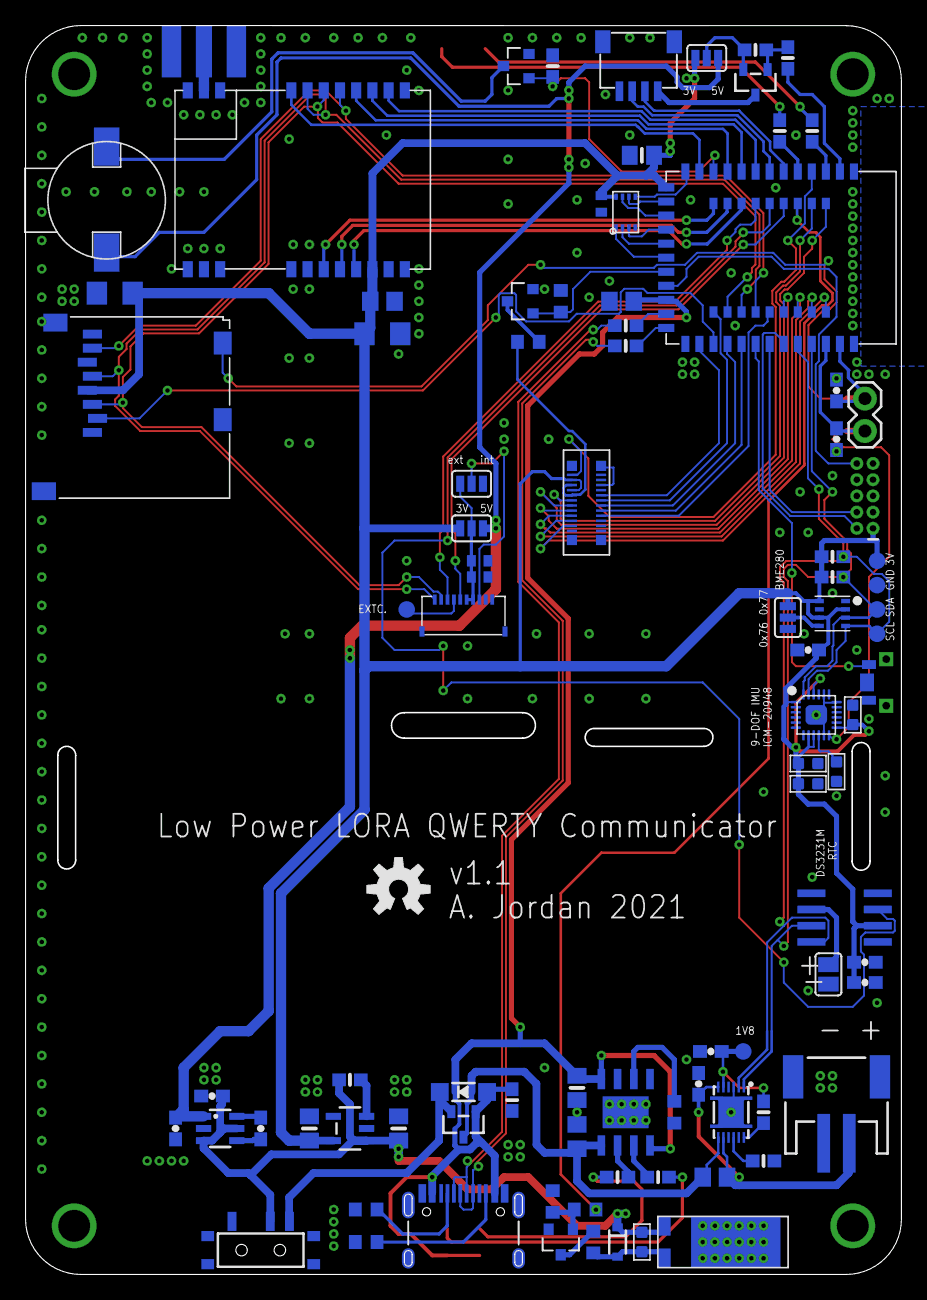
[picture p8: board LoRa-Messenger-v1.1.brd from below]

Board: 2 copper layers, 68.6 x 97.8 mm, 98 parts (91 on the bottom side), 94 nets.

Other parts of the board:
U$77: OSHW-LOGO-M

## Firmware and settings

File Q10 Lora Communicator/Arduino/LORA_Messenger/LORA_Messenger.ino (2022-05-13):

/*********************************************************************
  Code Base for the ultimate LORA QWERTY COMMUNICATOR project
  The Feather nRF52840 bootloader was installed (the device uses the same button an the same 2 LEDs)
  However, the variant.h and variant.cpp files of the feather board have been heavily modified.
  The pin numbering now just goes from 0 to 47 (P0.00 to P1.15) which is much easier to work with.

  Already working:
  -LS027B7DH01 400x240 memory LCD
  -Blackberry Q10 keyboard with backlight
  -BLE Stuff
  -BQ27441 Lithium Fuel Gauge
  -Buzzer
  -vibration motor
  -SX1262 TX and RX
  -BME280
  -DS3231M RTC
  -MPU9250 9-DOF IMU (hardware bug had to be corrected - switched I2C address to 0x69, else it collides with the DS3231 (0x68))
  -GD25Q16CE QSPI flash (works with mass storage TinyUSB test sketch)
  -GPS via tinyGPSPlus
  
  ToDo:
  -SD card - 
  
*********************************************************************/
#include <Arduino.h>
#include <Adafruit_TinyUSB.h> // for Serial
#include <Adafruit_GFX.h>
#include <Adafruit_SharpMem.h>
#include <SPI.h>
#include <Wire.h>
#include <RadioLib.h>
#include <SparkFunBQ27441.h>
#include <bluefruit.h>
#include "SparkFunBME280.h"
#include <DS3231M.h> //Written by Arnd <Zanshin_Github@sv-zanshin.com> / https://www.github.com/SV-Zanshin
//#include "MPU9250.h"
#include <MPU9250_WE.h>
#define MPU9250_ADDR 0x69 //changed it because the DS3231M also has 0x68!!
#include <TinyGPSPlus.h>

#include <Fonts/FreeSans9pt7b.h> 
#include <Fonts/FreeSans12pt7b.h>
#include <Fonts/FreeSans18pt7b.h>
#include <Fonts/FreeSans24pt7b.h>
//display.setFont(&FreeSans12pt7b);
#define BLACK 0
#define WHITE 1
#define TIME_ZONE 2 //what you need to add to UTC time

//#define SPI_MISO         15
//#define SPI_MOSI         13
//#define SPI_SCK          14
//Q10 keyboard defines
#define col1    16
#define col2    33
#define col3    17
#define col4    39
#define col5    24

#define row1    22
#define row2    35
#define row3    37
#define row4    20
#define row5    46
#define row6    44
#define row7    45
//PIN defines
#define IMU_INT       9
#define RTC_INT       40
#define PIN_BUZZER    31
#define GPS_ON        43 //LOW means on
#define MOT           25 //HIGH means ON
#define K_BLT         19 //HIGH means ON
#define DISP_CS       27
#define DISP_DISP     11
#define BTN           34 
#define SD_CS         32
#define SD_DET        10

#define DIO1 (28)
#define DIO2 (8)
#define TXEN (6)
#define RXEN (26)
#define L_SS (4)
#define BUSY (29)
#define L_RST (30)

//-------------------menue variables-------------------
//in order to add a new app you have to:
//add the name to appNames String array, take care of the order
//create a boolean "insideFuncXXX"
//add a "case" in the appropriate order to void ok_callback(void) ISR
//add an if statement with function call in loop()
//create the app function inside a new .ino file ("add new tab") ideally named appFuncXXX (easier to find)
//in the sketch folder with the following structure:
/*
  void funcXXX(){
  //start sequence
  //display Stuff, initialize....
  display.clearDisplay();

  display.setTextSize(3); //standard font is 5x8, so scale it by 3 ->15x24
  display.setCursor(5, 0);
  display.setTextColor(LCD_COLOR_WHITE);
  display.println("funcXXX");
  display.refresh();
  while (insideSubMenue) { //the back button terminates the loop
    //loop of the APP
    readKeyboard();
    readWASD();
    // ...
    delay(100); //get some sleep else the app hangs!
   }
   insideFuncXXX=false;
  displayMenue(menueIndex);
  }
*/
//note: since the project structure is based on freeRTOS and is callback-driven, not all app code is inside this app function
//for example the button callbacks and bluetooth functions have to be adapted
unsigned long prevStepCount = 0;
byte menueIndex = 0;
String appNames [] = {"LORA Chat","GPS","Sensor Data","BLE Sensors", "Settings"}; //enter your app names in correct order
#define NUMITEMS(arg) ((unsigned int) (sizeof (arg) / sizeof (arg [0]))) // number of items in an array
byte maxMenueIndex = NUMITEMS(appNames) - 1;  //the actual nuber of apps minus one
boolean insideLORAchat = false;
boolean insideGPS = false;
boolean insideSensorData = false;
boolean insideSettings = false;
boolean insideBLEsensors = false;
//------------------------------------------------------
boolean booting, insideMenue, insideSubMenue, centralConnected, peripheralConnected, charging, notificationHere = false;
boolean inMotion = false;
String notificationString = "";
//booleans for WASD navigation. They are changed in readKeyboard() and call the dn_callback etc.
boolean nav_up=0;
boolean nav_dn = 0;
boolean nav_right=0;
boolean nav_left=0;
boolean enter = 0;
boolean alt_for_wasd = 0;

int minorHalfSize; // 1/2 of lesser of display width or height
const uint8_t  SPRINTF_BUFFER_SIZE {32};  ///< Buffer size for sprintf() (RTC stuff)
//unsigned int year, month, day, hour, minute,second;  // Variables to hold parsed date/time


// Set BATTERY_CAPACITY to the design capacity of your battery.
const unsigned int BATTERY_CAPACITY = 1100; //
unsigned int soc = 0;
// flag to indicate that a packet was received
volatile bool receivedFlag = false;
unsigned long bltTimeout = 0;
boolean incomingMsg = false;
boolean ledState=false;
// disable interrupt when it's not needed
volatile bool enableInterrupt = true;

//KEYBOARD STUFF
char buf[6][21];
short int pos = 0;
char oldchr = 0;
byte shiftlock = 0; // set/unset by pressing shift and letting it go rather than using it as a modifier for another key
byte shiftlockchanged = 0; // helper
unsigned long time = 0; // keypad repetition interval
byte displaychanged = 1;
byte curline = 0;

//create instances of the components
Adafruit_SharpMem display(&SPI, DISP_CS, 400, 240);
SX1262 lora = new Module(L_SS, DIO1, -1, BUSY);
BME280 bme280; //address is set to 0x76
DS3231M_Class DS3231M;
//MPU9250 mpu;
MPU9250_WE myMPU9250 = MPU9250_WE(MPU9250_ADDR);
// The TinyGPSPlus object
TinyGPSPlus gps; 

// BLE Service
BLEDfu  bledfu;  // OTA DFU service
BLEDis  bledis;  // device information
BLEUart bleuart; // uart over ble
BLEBas  blebas;  // battery

SoftwareTimer screenUpdateTimer;

// *******************************************************SETUP*****************************************************************
void setup(void)
{
  Serial.begin(9600);
  delay(3000);
  Serial.println("Hello!");
 Serial1.begin(9600); //hardware UART for GPS
  //----------------INIT all the I2C sensors--------------------------
  setupBQ27441(); //WTF, Serial and the fuel gauge has to be initialized prior to the pins....
  soc = lipo.soc();  // Read state-of-charge (%)
  delay(100);
  setupBME_RTC_IMU();
  
  //KEYBOARD STUFF 
  // initialize our 8 lines of text
  for (int i = 0; i < 8; i++) buf[i][0] = 0;

  setupPins();

  setupLORA();

  //----------------DISPLAY INIT--------------------------
  // start & clear the display
  display.begin();
  display.clearDisplay();
  // Several shapes are drawn centered on the screen.  Calculate 1/2 of
  // lesser of display width or height, this is used repeatedly later.
  minorHalfSize = min(display.width(), display.height()) / 2;

  //test display
  testdrawchar();
  display.refresh();
  delay(1000);
  display.clearDisplay();

  //----------------TESTS--------------------------
  /*
notificationAlarm();
  */
  
  //------------------------------SOFTWARE TIMERS-----------------------------------
    // Configure the timer with 1000 ms interval, with our callback
  screenUpdateTimer.begin(1000, screenUpdateTimer_callback);

  // Start the timer
  screenUpdateTimer.start();

  setupBLE();

  Serial.println("Position you MPU9250 flat and don't move it - calibrating...");
  delay(1000);
  myMPU9250.autoOffsets();
  Serial.println("Done!");
  myMPU9250.setSampleRateDivider(5);
  myMPU9250.setAccRange(MPU9250_ACC_RANGE_2G);
  myMPU9250.enableAccDLPF(true);
  myMPU9250.setAccDLPF(MPU9250_DLPF_6);  


}

// *******************************************************LOOP*****************************************************************
void loop(void)
{
  //printBatteryStats();
  //keep display backlight on for some seconds after incoming message
  if ((millis() - bltTimeout) > 5000 && incomingMsg == true) {
    digitalWrite(K_BLT, LOW);
    incomingMsg = false;
  }

  //----------------send data from serial and BLE via LORA--------------------------
  // Forward data from HW Serial to BLEUART
  while (Serial.available())
  {
    // Delay to wait for enough input, since we have a limited transmission buffer
    delay(2);

    uint8_t buf[64];
    int count = Serial.readBytes(buf, sizeof(buf));
    bleuart.write( buf, count );
  }
  if (bleuart.available() > 0) {
    int BLEbytes = 0;
    uint8_t BLEbuf[64];
    // Forward from BLEUART to HW Serial
    while ( bleuart.available() )
    {
      uint8_t ch;
      ch = (uint8_t) bleuart.read();
      Serial.write(ch);
      BLEbuf[BLEbytes] = ch;
      BLEbytes++;
    }

    //now transmit via LORA
    prepareTX();
    Serial.print(F("[SX1262] Transmitting packet ... "));

    // you can transmit C-string or Arduino string up to
    // 256 characters long
    // NOTE: transmit() is a blocking method!
    //       See example SX126x_Transmit_Interrupt for details
    //       on non-blocking transmission method.
    //int state = lora.transmit("Hello World!");

    // you can also transmit byte array up to 256 bytes long
    int state = lora.transmit(BLEbuf, BLEbytes + 1);

    if (state == ERR_NONE) {
      // the packet was successfully transmitted
      Serial.println(F("success!"));

      // print measured data rate
      Serial.print(F("[SX1262] Datarate:\t"));
      Serial.print(lora.getDataRate());
      Serial.println(F(" bps"));
      delay(200);
      prepareRX();
    } else if (state == ERR_PACKET_TOO_LONG) {
      // the supplied packet was longer than 256 bytes
      Serial.println(F("too long!"));
    } else if (state == ERR_TX_TIMEOUT) {
      // timeout occured while transmitting packet
      Serial.println(F("timeout!"));
    } else {
      // some other error occurred
      Serial.print(F("failed, code "));
      Serial.println(state);
    }
  }
  //----------------LORA RECEIVE ROUTINE--------------------------
  // check if the flag is set
  if (receivedFlag) {
    // disable the interrupt service routine while
    // processing the data
    enableInterrupt = false;
    // reset flag
    receivedFlag = false;
    // you can read received data as an Arduino String
    String str;
    int state = lora.readData(str);
    // you can also read received data as byte array
    /*
      byte byteArr[8];
      int state = lora.readData(byteArr, 8);
    */
    if (state == ERR_NONE) {
      // packet was successfully received
      Serial.println(F("[SX1262] Received packet!"));

      // print data of the packet
      Serial.print(F("[SX1262] Data:\t\t"));
      Serial.println(str);
      bleuart.print(str); //send via BLE
      display.clearDisplay();
     // digitalWrite(K_BLT, HIGH);
      notificationAlarm();
      display.setFont(&FreeSans9pt7b);
display.clearDisplay();
       display.setTextColor(BLACK);
      //display.setTextSize(1);
      display.setCursor(10, 30);
      display.print(str);
      display.println("     ");
      
      display.print("RSSI: ");
      display.print(lora.getRSSI());
      display.println(" dBm  ");
      display.print("SNR: ");
      display.print(lora.getSNR());
      display.println(" dB  ");
      display.refresh();
      bltTimeout = millis();
      incomingMsg = true;

      // print RSSI (Received Signal Strength Indicator)
      Serial.print(F("[SX1262] RSSI:\t\t"));
      Serial.print(lora.getRSSI());
      Serial.println(F(" dBm"));
      // print SNR (Signal-to-Noise Ratio)
      Serial.print(F("[SX1262] SNR:\t\t"));
      Serial.print(lora.getSNR());
      Serial.println(F(" dB"));
      
    } else if (state == ERR_CRC_MISMATCH) {
      // packet was received, but is malformed
      Serial.println(F("CRC error!"));
    } else {
      // some other error occurred
      Serial.print(F("failed, code "));
      Serial.println(state);
    }
    // put module back to listen mode
    lora.startReceive();
    // we're ready to receive more packets,
    // enable interrupt service routine
    enableInterrupt = true;
  }

 
  
  
//----------------housekeeping --------------------------
  readKeyboard();
  readWASD();
  /*
  display.setCursor(10, 200);
  display.setTextColor(BLACK, WHITE);
  display.setTextSize(2);
  for (int i = 0; i < 6; i++)
    display.print(buf[i]);
  display.refresh();
*/
//----------------MENU STUFF ----------------

    

    if (insideLORAchat) {
    appLORAchat();
  }

  if (insideGPS) {
    appGPS();
  }

  if (insideSensorData) {
    appSensorData();
  }

  if (insideSettings) {
    appSettings();
  }

  if (insideBLEsensors) {
    appBLEsensors();
  }

  //refresh dislay approx. every minute. Not perfect, I know.
//  if (second() == 0)
 //   if (!insideMenue) mainScreen();

  
  delay(100); //remember: delay=sleep in the nrf52 RTOS-based core
}



// *******************************************************FUNCTIONS*****************************************************************



void btn_callback(void)
{
  ledState=!ledState;
  digitalWrite(LED_BUILTIN, ledState);

  if (!insideMenue && !insideSubMenue) {
    insideMenue = true;
    menueIndex = 0;
    displayMenue(menueIndex);
  }
}

void screenUpdateTimer_callback(TimerHandle_t xTimerID)
{
  // freeRTOS timer ID, ignored if not used
  (void) xTimerID;

}

void ok_callback(void)
{

  //digitalToggle(BLT);
  if (insideMenue && !insideSubMenue) {
    insideSubMenue = true;
    switch (menueIndex) {
      case 0:
        //enter BLE scan function
        insideLORAchat = true;
        break;

      case 1:
        //Show data of connected BLE UART sensors
        insideGPS = true;
        break;

      case 2:
        insideSensorData = true;
        break;


      case 3:
        insideBLEsensors = true;
        break;

        
      case 4:
        insideSettings = true;
        break;

      case 5:
      /*
        clearBlack();
        display.setTextSize(2);
        display.setCursor(2, 70);
        display.setTextColor(WHITE);
        display.println("Shutdown...");
        display.setTextColor(WHITE);
        display.println("press OK --->");
        display.println("to turn on");
        display.refresh();
        delay(3000); //some delay to make sure the device does not reboot again immediately
        clearBlack();
        display.refresh();
        shutdownSystem();
        */
        break;

    }
  } else if (!insideMenue && !insideSubMenue) {
    insideMenue = true;
    menueIndex = 0;
    displayMenue(menueIndex);
  }

}

void bck_callback(void)
{

  //turnOff = true;
  //shutdownSystem();
  if (insideSubMenue) {
    insideSubMenue = false;
    displayMenue(menueIndex);
  } else if (insideMenue && !insideSubMenue) {
    insideMenue = false;
    mainScreen();
  } else {
    //what to do while in mainScreen
  }

}

void dn_callback(void)
{
  //enterOTADfu();
  if (insideMenue && !insideSubMenue) {
    if (menueIndex >= maxMenueIndex) menueIndex = maxMenueIndex; else menueIndex++;
    displayMenue(menueIndex);
  } else if (insideSubMenue) {
    //it depends
    //if (insideGestRecFunc) {
      //this decides whether we record or recognize gestures
    //  if (!recordGest) recordGest = true; else recordGest = false;

   // }
  } else {
   // digitalToggle(BLT);
  }

}
void up_callback(void)
{
  if (insideMenue && !insideSubMenue) {
    if (menueIndex <= 0) menueIndex = 0; else menueIndex--;
    displayMenue(menueIndex);
  } else if (insideSubMenue) {
    //it depends

  } else {
   // notificationHere = false; //delete the notification window on the main screen.
   // notificationString = "";
    mainScreen();
  }
}

void readWASD(){
  
    if (nav_up) up_callback();
    if (nav_dn) dn_callback();
    if (nav_right) ok_callback();
    if (nav_left) bck_callback();
}

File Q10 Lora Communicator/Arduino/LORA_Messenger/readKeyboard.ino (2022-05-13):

void readKeyboard(){
  //https://forum.arduino.cc/t/interfacing-blackberry-q10-keypad-to-arduino-and-the-oled-typewriter/342989
byte alt = 0; // flag for alt modifer key, unimplemented.
  byte sym = 0; // flag for symbol modifer key
  byte shift = 0; // flag for shift modifier key
  byte shl = 0; // left shift for shift lock detection
  byte shr = 0; // right shift for shift lock detection
  char chr = 0; // current character
  char symb = 0; // current symbol
nav_up=0;
nav_dn = 0;
nav_right=0;
nav_left=0;
enter=0;

  // figure out the current scan code, if any, and any modifier keys, if any
  pinMode(col1, OUTPUT); 
  digitalWrite(col1, LOW);
  delay(1);
  if (digitalRead(row1)==0) {chr = 'Q'; symb='#';}
  if (digitalRead(row2)==0) {chr = 'W'; symb='1'; nav_up=1; } //if (insideMenue) up_callback();
  if (digitalRead(row3)==0) {sym = 1;}             // symbol modifier key
  if (digitalRead(row4)==0) {chr = 'A'; symb='*'; nav_left=1; } //if (insideMenue) bck_callback();
  if (digitalRead(row5)==0) {alt = 1; alt_for_wasd = !alt_for_wasd;}             // alt modifier key - it enables different usage scenarios of the keyboard, f.e. wasd navigation
  if (digitalRead(row6)==0) {chr = ' '; symb=' ';}
  if (digitalRead(row7)==0) {chr = '~'; symb='0';}
  
  pinMode(col1, INPUT); 
  pinMode(col2, OUTPUT); 
  digitalWrite(col2, LOW);
  delay(1); //the nrf52840 needs those delays
  if (digitalRead(row1)==0) {chr = 'E'; symb='2';}
  if (digitalRead(row2)==0) {chr = 'S'; symb='4'; nav_dn=1;} //if (insideMenue) dn_callback();
  if (digitalRead(row3)==0) {chr = 'D'; symb='5'; nav_right=1;} //if (insideMenue) ok_callback();
  if (digitalRead(row4)==0) {chr = 'P'; symb='@';}
  if (digitalRead(row5)==0) {chr = 'X'; symb='8';}
  if (digitalRead(row6)==0) {chr = 'Z'; symb='7';}
  if (digitalRead(row7)==0) {shift = 1; shl = 1;}  // shift modifier key
  
  pinMode(col2, INPUT); 
  pinMode(col3, OUTPUT); 
  digitalWrite(col3, LOW);
 delay(1);
  if (digitalRead(row1)==0) {chr = 'R'; symb='3';}
  if (digitalRead(row2)==0) {chr = 'G'; symb='/';}
  if (digitalRead(row3)==0) {chr = 'T'; symb='(';}
  if (digitalRead(row4)==0) {shift = 1; shr = 1;}  // shift modifier key
  if (digitalRead(row5)==0) {chr = 'V'; symb='?';}
  if (digitalRead(row6)==0) {chr = 'C'; symb='9';}
  if (digitalRead(row7)==0) {chr = 'F'; symb='6';}
  
  pinMode(col3, INPUT); 
  pinMode(col4, OUTPUT); 
  digitalWrite(col4, LOW);
 delay(1);
  if (digitalRead(row1)==0) {chr = 'U'; symb='_';}
  if (digitalRead(row2)==0) {chr = 'H'; symb=':';}
  if (digitalRead(row3)==0) {chr = 'Y'; symb=')';}
  if (digitalRead(row4)==0) {chr = '|'; symb='|'; enter=1;} // this should be a CR but I am substituting a pipe for CR in this implementation
  if (digitalRead(row5)==0) {chr = 'B'; symb='!';}
  if (digitalRead(row6)==0) {chr = 'N'; symb=',';}
  if (digitalRead(row7)==0) {chr = 'J'; symb=';';}
  
  pinMode(col4, INPUT); 
  pinMode(col5, OUTPUT); 
  digitalWrite(col5, LOW);
  delay(1);
  if (digitalRead(row1)==0) {chr = 'O'; symb='+';}
  if (digitalRead(row2)==0) {chr = 'L'; symb='"';}
  if (digitalRead(row3)==0) {chr = 'I'; symb='-';}
  if (digitalRead(row4)==0) {chr = 8;}            // backspace
  if (digitalRead(row5)==0) {chr = '$'; symb='`';}
  if (digitalRead(row6)==0) {chr = 'M'; symb='.';}
  if (digitalRead(row7)==0) {chr = 'K'; symb='\'';}
  
  pinMode(col5, INPUT); 
if(alt_for_wasd==false){
  if (chr != oldchr)
    if (chr==8)    // Deal with backspace  
    {
      if ((pos > 0) || (curline > 0)) // don't underflow our buffer
      {
          if (pos==0) {pos=20; curline--;}
          buf[curline][--pos] = 0;
          time = millis();
          displaychanged = 1;
      }
    }
    else if (chr !=0)
    {
      if (curline < 6) // don't overflow our buffer      
      {
        if (sym==1) // if the symbol key is pressed, put it in the buff as a symbol
          buf[curline][pos] = symb;
        // enter raw/upper case character if shift is selected or it is not a shiftable character
        else if (shift==1 || shiftlock==1 || chr=='$' || chr==' ' || chr=='~' || chr == 13)
          buf[curline][pos] = chr;
        // otherwise enter as a lower case character
        else
          buf[curline][pos] = (chr+32);    
          
        // advance end of buffer
        buf[curline][++pos] = 0;
        if (pos>19) {curline++; pos=0;}
        time = millis();
        displaychanged = 1;
      }
    }
  
  // Pressing both shift keys together is taken as a shift lock operation
  
  if (shl == 1 && shr == 1 && shiftlockchanged == 0)
  {
    shiftlock = (shiftlock==0)?1:0;
    shiftlockchanged = 1;  // prevent multiple shift lock activations
  }
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

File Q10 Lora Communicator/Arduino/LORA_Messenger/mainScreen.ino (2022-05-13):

void mainScreen() {
  if (!insideMenue) {
    display.clearDisplay();
   // display.setTextSize(3); //standard font is 5x8, so scale it by 3 ->15x24
   display.setFont(&FreeSans18pt7b);

  display.setCursor(25, 30);
  display.setTextColor(BLACK);
  display.println("Main Screen");
  display.refresh();
  }

}

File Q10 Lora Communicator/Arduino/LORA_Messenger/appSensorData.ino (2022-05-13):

void appSensorData() {
  //start sequence
  //display Stuff, initialize....
  display.clearDisplay();
  //display.setTextSize(3); //standard font is 5x8, so scale it by 3 ->15x24
  display.setFont(&FreeSans18pt7b);
  display.setCursor(25, 30);
  display.setTextColor(BLACK);
  display.println("Sensor Data");
  display.refresh();
  while (insideSubMenue) { //the back button terminates the loop
    readKeyboard(); //navigate with "WASD"
    readWASD();
    //loop of the APP
display.clearDisplay();
    //----------------DRAWING AND MEASURING STUFF --------------------------
    unsigned int soc = lipo.soc();
    display.setTextColor(BLACK);
    //display.setTextSize(1);
    display.setFont(&FreeSans9pt7b);

    display.setCursor(330, 20);
    //display.print("    ");
    //display.refresh();
    display.setCursor(330, 20);
    display.print(soc);
    display.print("% ");
    display.setCursor(330, 40);
    int current = lipo.current(AVG); // Read average current (mA)
    //display.print("     ");
    //display.refresh();
    display.setCursor(330, 40);
    display.print(current);
    display.print("mA  ");
    display.refresh();
    delay(5);
    unsigned int hum =  bme280.readFloatHumidity();
    display.setCursor(330, 60);
    display.print(hum);
    display.print("%  ");
    display.refresh();
    delay(5);
    DateTime       now = DS3231M.now();  // get the current time from device
    // Use sprintf() to pretty print the date/time with leading zeros
    char output_buffer[SPRINTF_BUFFER_SIZE];  ///< Temporary buffer for sprintf()
    sprintf(output_buffer, "%04d-%02d-%02d %02d:%02d:%02d", now.year(), now.month(), now.day(),
            now.hour(), now.minute(), now.second());
    display.setCursor(10, 40);
    display.print(output_buffer);
    display.refresh();
    delay(5);

    xyzFloat angles = myMPU9250.getAngles();
    //mpu.update();
    display.setCursor(10, 60);
    // float roll = mpu.getRoll();
    display.print(angles.x);
    display.print(" ");
    //float pitch = mpu.getPitch();
    display.print(angles.y);
    display.print(" ");
    // float yaw = mpu.getYaw();
    display.print(angles.z);
    display.print("     ");
    display.refresh();

    delay(400); //get some sleep else the app hangs!
  }
  insideSensorData = false;
  displayMenue(menueIndex);
}

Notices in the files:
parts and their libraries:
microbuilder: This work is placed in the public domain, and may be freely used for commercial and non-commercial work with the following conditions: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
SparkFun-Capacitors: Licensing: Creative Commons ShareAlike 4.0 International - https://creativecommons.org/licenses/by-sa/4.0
